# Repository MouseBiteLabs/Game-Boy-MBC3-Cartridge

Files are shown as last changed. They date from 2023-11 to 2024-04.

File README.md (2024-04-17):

# Game Boy MBC3 Cartridge

This is my design of a flashable MBC3-based cartridge for the Game Boy. The MBC3 mapper improves a lot over the MBC1, and includes a real-time clock for everyone's favorite battery-sucking game.... Mary Kate and Ashley Pocket Planner! Oh, and Pokemon.

This circuit board should cover most, if not all, MBC3 games. The features are as follows:

- Able to make games up to 2 MB in size, that use up to 256 Kbit of RAM
- Compatibility with all four of the popular Game Boy battery management ICs - MM1026, MM1134, BA6129, and BA6735
- The option to add battery backup to the cartridge *without* the need of the original battery management ICs
- Fully compatible with the <a href="https://www.gbxcart.com/">GBxCart RW</a> so you can transfer games and save files to and from the board
- 
assemblepic

boardscan3

All gerbers and source files can be found in this repo, as this project is fully open source. Technical documentation of the board can be found in the Technical folder.

## Important Things Before You Start

1) To use this board, you need to have an original Game Boy game that uses an MBC3 mapper chip. <a href="https://catskull.net/gb-rom-database/">You can find a list of games and their mappers here</a>. Use the search function. Please note the RAM is in bytes, not bits. Since SRAM in this repo is defined in bits, you need to convert by multiplying the number of bytes by 8.
2) You will need to remove the MBC3 from your donor cartridge for use on this board. This will require a hot air rework station or a hot plate. There's a list below of other parts you can re-use from the donor cartridge.
3) When soldering parts on, it's a good idea to put kapton tape or otherwise cover the bottom cartridge edge. You do not want to get solder on the cartridge contacts.
4) I am not responsible for any damage you do to your self or your property. Attempt this project at your own risk.
5) I do not guarantee design compatibility. You may encounter issues with certain games. There is also a chance I have made an error in the design or the BOM - if this is the case, I will do everything I can to address the problem as quickly as possible.
6) If you are using this board to make games other than for personal use, you must have permission from the originator to use and distribute any ROM images or other related material. You are responsible for making sure you adhere to any license requirements.

DO NOT use my circuit boards for profiting from stolen work - this especially includes homebrew content, ROM hacks, and using fan-made labels without permission from the originator. **Support original creators!**

## Board Characteristics and Order Information

The zipped folder contains all the gerber files for this board. The following options **must** be chosen when ordering boards for yourself.

- Thickness: 0.8mm
- Surface Finish: ENIG
- Gold Fingers: Yes, 30° chamfer

**Add this note to orders:** "The milling.gbr layer indicates where an unplated slot should be added to the board. Please add an unplated slot as indicated."

**I sell this blank circuit board on Etsy, so you don't have to buy a bunch of multiples if you don't want to.** (Click the banner!)

<a href="https://mousebitelabs.etsy.com/listing/1605239014/game-boy-cartridge-pcb-mbc3">PCB from Etsy</a> 

You can use the zipped folder at any board fabricator you like. You may also buy the board from PCBWay using this link (disclosure: I receive 10% of the sale value to go twoards future PCB orders of my own):

<a href="https://www.pcbway.com/project/shareproject/Game_Boy_MBC3_Cartridge_a4f7b749.html">PCB from PCBWay</a>

<a href="https://oshpark.com/shared_projects/6rPI4Bk8">The board is also listed on OSH Park as well.</a> **Be sure to get them in 0.8mm thickness if you order from here.**

## Required Equipment

The EEPROMs on the board needs to be programmed somehow. I recommend using the GBxCart, as mentioned. These boards are fully compatible with it, and it makes reflashing games extremely easy using <a href="https://github.com/lesserkuma/FlashGBX">lesserkuma's FlashGBX software</a>.

Alternatively, you can buy an EEPROM programmer with a TSOP adapter. The downside to this method is that you have to desolder the chip every time you want to program it. The <a href="https://flashcatusb.com/">FlashcatUSB</a> is one popular option in retro spaces.

## Battery Safety

When assembling a board, I recommend populating all the parts *except* the battery, and getting it to run initially without it. This is to make it easier to fix any solder connections that might need fixing, without having to worry about getting the battery hot. And if you need to rework anything near the battery after you've put it on the board, be safe and remove it before putting a hot soldering iron next to it.

And this should go without saying, but if you're assembling these boards with a hot plate or hot air, *do not* solder the battery on this way. You should use an iron, and keep heat off of the battery as much as possible. 

(Also check polarity!)

## Board Configurations

The board comes with five sets of jumper pads for solder bridges. SJ3, SJ5, and SJ6 require you to solder bridge the middle pad either to the left or right pads. SJ1 and SJ4 are configured by either leaving them alone or bridging them with solder. Here are the situations where you need to add solder bridges.

### Making Games Without SRAM or Battery (SJ1 and SJ4)

Solder bridge SJ1 and SJ4 if your game does not use any SRAM or battery. I don't believe there were ever any MBC3 games made *without* SRAM, but if you wanted to... remove it for some reason, you can.

### MBC3 Type Select (SJ3)

The MBC3 chip you use from the donor cartridge can be one of a few different types:

- If your MBC3 doesn't have a revision letter on it (it just says "MBC3" on it) then bridge the middle pad of SJ3 to the left. (You will also need to populate Q1!)
  - If you're using a revision-less MBC3, and are making a game that requires a battery, you should use a donor MM1026, MM1134, BA6129, or BA6735 battery management IC instead of the replacement TPS3613.
- If your MBC3 *does* have a revision letter, such as MBC3A or MBC3B, then bridge the middle pad of SJ3 to the right.



*[Images of MBC3 chips from <a href="https://gbhwdb.gekkio.fi/cartridges/mbc3.html">Game Boy Hardware Database</a>.]*

### RAM Size Selection (SJ5 and SJ6, or SW1)

These jumpers are located underneath the MBC3 chip, and labeled "64K" and "256K". Solder them to configure the amount of RAM your cart uses. You must configure these pads for every game you make, unless you do not need RAM. <a href="https://catskull.net/gb-rom-database/">You can find a list of games here with their respective RAM sizes.</a>

- If the game you're making uses 256 Kbit of RAM, then solder the middle pads of the two jumper sets to the right pads.
- If the game you're making uses 64 Kbit of RAM, then solder the middle pads of the two jumper sets to the left pads.
- SJ5 and SJ6 must be soldered in the same direction.
- The footprint of these selection pads should allow for a DPDT switch, part number CAS-220A1, to be placed on these pads instead of having to bridge the pads with solder.

Note that you can make games that only require 64 Kbit of RAM and still use a 256 Kbit SRAM chip. You still need to configure the jumpers to the 64 Kbit setting, though.



### Games Without a Real-Time Clock

If your game does *not* use the RTC function with the crystal X1, then you need to bridge the pads of Z1 (which is called C3 on v1.3 and earlier).



## Test Points and Final Checkout

On the back of the board are five test points. Here's where they are connected:

- TP1: SRAM supply voltage
- TP2: Battery voltage (after R1)
- TP3: Battery voltage (positive terminal of battery)
- TP4: Ground
- TP5: VCC input voltage

After you assemble your game, you should measure the current out of the battery. But first, you should program it with the GBxCart, or if you programmed the EEPROM separately, put it into a Game Boy and cycle power once. Then, flip the PCB upside down on a non-conductive surface (not your leg), and set your multimeter in DC millivolts (or volts). Put the positive probe on TP3 and the negative probe on TP2. If you used a 10kΩ for R1, as indicated in the BOM, you should read a voltage in the single or tens of millivolts for non-RTC games, or up to 40 mV for games using a real-time clock. If you have something much higher, especially voltages above 40mV, then you likely have an issue or short circuit on the board somewhere.

**Note: You need to power up the game at least once before battery currents will make sense - the battery management ICs can start up in an unknown state before applying main power to the board.**

To estimate battery life, see <a href="https://github.com/MouseBiteLabs/Game-Boy-MBC3-Cartridge/tree/main/Technical#estimating-battery-life">this section in the Technical Design Document</a>, or for more in-depth analysis, <a href="https://hackaday.io/project/11864-tritiled/log/72554-determining-maximum-runtime-176-to-202-years-cr2032">this Hackaday post</a>.

### Current Draw Measurements

The revision of MBC3 chip you are using will influence the current draw out of the battery when the game is off, and thus how long your battery life will last. Using the real-time clock function on the MBC3 will draw more current than if you do not.

For the test set up, I am replacing the battery with a regulated DC power supply set for 3 VDC for consistency, on a cart board with an MM1134 chip for U4, and brand new AS6C62256 SRAM. The "no RTC" measurements have Z1 (or C3) shorted, and the "with RTC" measurements have R2, C2, Z1, and X1 populated. I am using a Fluke 117 Multimeter in DC mV mode for measurements.

| Rev | P/N | Current draw (without RTC) | Battery Life Estimate (no RTC, CR2025) | Current draw (with RTC) | Battery Life Estimate (RTC, CR2025)  | Battery Life Estimate (RTC, CR2032) |
| ----- | --- | --- | --- | --- | --- | --- |
| MBC3  | LR385364 | 0.2 uA | >50 years | 1.8 uA | 10 years | 14 years |
| MBC3  | BU3631K  | 0.6 uA | 31 years | 1.6 uA | 12 years | 16 years |
| MBC3  | P-1 | 0.4 uA | 47 years | 3.8 uA | 5 years | 7 years |
| MBC3A | LR38536B | 0.2 uA | >50 years | 1.5 uA | 13 years | 18 years |
| MBC3A | BU3632K  | 0.5 uA | 37 years | 1.5 uA | 13 years | 18 years |
| MBC3A | P-2 | 0.5 uA | 37 years | 3.9 uA | 5 years | 7 years |
| MBC3B | BU3634K  | 0.6 uA | 31 years | 1.5 uA | 13 years | 18 years |
| MBC3B | P-2 | 0.4 uA | 47 years | 3.7 uA | 5 years | 7 years |

*Note: The SRAM I used, AS6C62256, drew 0.05 uA by itself for these tests. Your current draw may vary depending on the SRAM you are using.*

### Why not FRAM?

This board is only suitable for using SRAM. One downside to SRAM, if you haven't figured it out yet, is that you need a battery to keep the SRAM powered on even when the game is turned off. So eventually the battery will die, and your save data is lost. Some people have used FRAM, or Ferroelectric RAM, to keep save data around even after the battery dies (specifically, the popular part that's used for FRAM carts is the FM18W08). But, using this FRAM chip has a handful of downsides, and the benefit of keeping save data after the battery dies *in my opinion* does not outweigh the cons, which are as follows:

1) Quality, new stock, 5V tolerant FRAM is expensive ($12+ per part).
2) Cheaper FRAM chips from eBay or Aliexpress are notoriously flaky (anecdotally, ~50% success rate).
3) FRAM memory access requires different chip select timing than SRAM, and the Game Boy expects SRAM, so it is not natively compatible with FRAM carts. The Gameboy Color specifically cannot (easily) be made to properly access FM18W08 chip. You *can* use an OR gate and add the CLK on the cart edge to try to achieve the necessary timing, but it only works (properly) for DMG/MGB/SGB, not the GBC. It usually *works* in practice for GBC, but it's technically a datasheet violation and can potentially cause issues in edge cases. <a href="https://github.com/Gekkio">(Thanks to gekkio for pointing this out!)</a>

Brand new SRAM chips are ~$3, and having the SRAM footprint also allows you to use SRAM from an original cart if desired. And other than the scenario where you are making a game with a real-time clock and are using an inefficient MBC3 variant (P-1 or P-2), you can easily get more than a decade of battery life. You're already assembling this cartridge; you can dump the save and replace the battery!

Note that this isn't to throw shade at any FRAM-based carts, but for me personally, it's more trouble than it's worth. If you just *need* FRAM, you can find other cart designs out there that have it, <a href="https://retrogamerepairshop.com/products/game-boy-2mb-32kb-fram-mbc3-with-rtc-flash-cartridge-by-hdr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">like this one!</a>

## Board Fitment

The shape of this board was originally meant to mimic original Game Boy circuit boards as closely as possible (v1.3 and earlier). Unfortunately, when placed in some aftermarket Game Boy cartridge shells (like those from Cloud Game Store), the circuit board has a lot of freedom to rotate around the main screw hole in the bottom-middle of the cartridge. This can cause misalignment when you put it in a Game Boy, which can cause a game to either not load properly (garbled Game Boy logo) or shut off the Game Boy because of a short circuit. This isn't *dangerous* or anything, just annoying.

In order to make the boards fit nicer in any kind of shell, for v1.4 I added extended tabs of circuit board material to the edges of the cartridges to keep it from rotating too much in shells, which was suggested to me by <a href="https://github.com/orangeglo">orangeglo</a>! (Thanks!)

If you're having trouble fitting the circuit board into a shell, because the tabs interfere with the cart edges, you can safely sand or trim them down as there is no copper within the tabs themselves. The only shell that appears to require any kind of trimming are Kitsch-Bent shells.

## Bill of Materials (BOM)

Your parts list will vary depending on the game you are trying to make, and what chips you have for the battery management (if any). **You cannot use both U4 and U5 - you must choose one or the other.** U4 comes from a donor cartridge, and U5 is a readily available aftermarket option.

Please carefully review the parts you need for the board you are trying to make. Do not add any parts to your build that don't appear in the column for the game you are making. This means you *cannot* populate every component on the board at the same time.

**NOTE: If you are *not* using the RTC function of the MBC3, you need to bridge the pads of Z1 (or C3) with solder.**

| Reference Designators | Value/Part Number | Package | Description | No save carts | Save carts with U4 | Save carts without U4 | Source |
| --- | --- | --- | --- | --- | --- | --- | --- |
| B1 | CR2032, CR2025, CR2016 | CR2032 | Backup Battery | | x | x | [https://mou.sr/3SeAzfT](https://mou.sr/3SeAzfT) |
| C1 | 0.1uF | 0603 | Capacitor (MLCC) | x | x | x | [https://mou.sr/3ENc15O](https://mou.sr/3ENc15O) |
| C2 | 15pF | 0603 | Capacitor (MLCC) | | If using RTC | If using RTC | https://mou.sr/3PPorjO |
| Z1 (or C3) | 15pF | 0603 | Capacitor (MLCC) | | If using RTC | If using RTC | https://mou.sr/3PPorjO |
| C4 | 0.1uF | 0603 | Capacitor (MLCC) | | x | | [https://mou.sr/3ENc15O](https://mou.sr/3ENc15O) |
| C5 | 0.1uF | 0603 | Capacitor (MLCC) | | x | x | [https://mou.sr/3ENc15O](https://mou.sr/3ENc15O) |
| C6 | 10uF | 0603 | Capacitor (MLCC) | | x | x | [https://mou.sr/3mZtSkF](https://mou.sr/3mZtSkF) |
| C7 | 0.1uF | 0603 | Capacitor (MLCC) | x | x | x | [https://mou.sr/3ENc15O](https://mou.sr/3ENc15O) |
| C8 | 0.1uF | 0603 | Capacitor (MLCC) | | | x | [https://mou.sr/3ENc15O](https://mou.sr/3ENc15O) |
| Q1 | 2N7002 | SOT-23 | N-Channel FET | | If MBC3 no rev | x | [https://mou.sr/3rgfh6J](https://mou.sr/3rgfh6J) |
| R1 | 10k | 0603 | Resistor | | x | x | [https://mou.sr/3riR7IH](https://mou.sr/3riR7IH) |
| R2 | 330k | 0603 | Resistor | | If using RTC | If using RTC | [https://mou.sr/3PZ2pvj](https://mou.sr/3PZ2pvj) |
| R8 | 10k | 0603 | Resistor | x | x | x | https://mou.sr/3riR7IH |
| R9 | 130k | 0603 | Resistor | | | x | [https://mou.sr/3MjXliy](https://mou.sr/3MjXliy) |
| R10 | 49.9k | 0603 | Resistor | | | x | https://mou.sr/3Q3NRZO |
| U1 | 29F016, 29F032, 29F033 | TSOP-48, TSOP-40 | Flash EEPROM | x | x | x | AliExpress or eBay |
| U2 | MBC3 | QFP-32 | MBC3 Mapper | x | x | x | Donor MBC3 Game Boy cartridge |
| U3 | AS6C6264, AS6C62256 | SOP-28 | SRAM | | x | x | [https://mou.sr/450klcY](https://mou.sr/450klcY) |
| U4 | MM1026, MM1134, BA6129, BA6735 | SOIC-8 | Battery Management | | x | | Donor Game Boy cartridge |
| U5 | TPS3613 | MSOP-10 | Battery Management | | | x | [https://mou.sr/45Ir2kh](https://mou.sr/45Ir2kh) |
| X1 | 32.768 kHz | Radial | Crystal Oscillator | | If using RTC | If using RTC | https://mou.sr/3ZteKuy |

*Note that C9 - C11 footprints are only included on the board for strange edge cases that may require them sometime in the future; do not populate! See the technical design document for more information.*

### Usable Donor Cartridge Parts

You can use a few parts from the donor cart on the new board to save some money. Note that you will generally get better reliability with new parts as opposed to old ones. For example: I have seen failed RAM chips from donors in the past.

1) **C1/Z1, C2, R2, X1: RTC Components** - You can move over these parts if you're using the real-time clock function. The two capacitors are the same value, so they are interchangeable. On games that *don't* use the RTC, you can't move "Z1" over, because it's a resistor on those boards. Also be careful that on my board, the RTC capacitors are designated as "Z1" (or "C3") and "C2" - don't accidentally move the wrong capacitors over from the donor board to these spots!
2) **U2: MBC3** - This one is required
3) **U3: SRAM** - You can use this part *only if* the game you're making uses the same or less amount of RAM that the donor cartridge does
4) **U4: Battery Management IC** - Using this is probably preferred over the TPS3613 because it'll save you money and parts to put on

You could probably transfer over most of the 0.1uF capacitors but they're pretty cheap anyway, so I generally just recommend buying new resistors and capacitors.

### Capacitors C9 to C11

If you want to experiment with the capacitors C9 to C11, see this info below. **Be aware that adding these components in some of my tests actually ***stopped*** games from working, so again, assume that if you have a problem it lies elsewhere first, because it almost certainly does.**
- C9 is a capacitor connected nearby the SRAM's /WE pin to GND. These were populated on some cartridges, and I believe have a value of approximately 1 nF (0.001 uF) based on measurements from an MBC1 board that used it.
- C10 is a capacitor connected from the cart edge /RESET pin to GND. A spot for this capacitor was included on some MBC1 carts, but I cannot locate an instance of it actually being used when looking through the gbhwdb. It does not appear on *any* MBC3 boards. I don't actually know what value this capacitor would need to be, so I am guessing 1 nF.
- C11 is a capacitor that I have added that was not used on any original Game Boy board. It connects to the SRAM's /CE pin, bypassing to GND. I have added this in the event incompatibilities arise with newer SRAM chips that have much faster speeds than older SRAM chips. This was a problem I encountered on some of my NES cartridges, so this is here just in case, but I have not found an instance where it's required.

## Things to Remember

- The footprint for the EEPROM is specifically for 29F016 - it has 48 pins. However, 29F032 and 29F033 are only 40 pin devices. They still work fine on the board though - place them in the center of the footprint, and leave the outer two pins on each corner empty
- The 29F016, 29F032, and 29F033 have been known to occasionally be defective upon arrival. They're either used, or new old stock, and usually only available from AliExpress.
- The footprint for the battery can fit a CR2032, CR2025, or CR2016 with solder tabs. The only difference is the mAh capacity (larger number = longer life). If you get Panasonic tabbed batteries, you may have to trim the battery tabs to make them fit on the footprint.
  - For untabbed coin cells, you can find battery retainer adapters online, <a href="https://retrogamerepairshop.com/products/hdr-game-boy-game-battery-retainer?variant=40511013290156">like this one,</a> but only for board revision v1.4. It will not fit on earlier revisions.
- For battery management, use either U4 *or* U5 and supporting components. **Do not** use U4 and U5 simultaneously on one board. They will interfere with each other.
- Generally, ROM sizes are conveyed in terms of kilo**bytes** and mega**bytes** (KB, MB). RAM size is usually conveyed in terms of kilo**bits** or mega**bits** (Kbit, Mbit). You can convert Kbit and Mbit to KB and MB by dividing Kbit or Mbit by 8. For example, 256 Kbit = 32 KB.
- You only need to provide ROM and RAM chips that have at least *or greater* the size of the game you are trying to make. That means you can use a 256 Kbit SRAM chip for a game that only requires 64 Kbit of RAM!

## Labels

If you want a Bucket Mouse branded label for your cartridge, look no further than <a href="https://krizdingus.com/mousebitelabs/">krizdingus's designs</a>. Special thanks to Kris for designing these, they look awesome! (If you are going to order/print these, use the high-res images hosted on his website, and *keep the labels for personal or non-commercial use only.*)



## Revision History

### v1.4
- Changed "C3" to "Z1"
- Reduced cart edge by 0.1 mm for better fitment
- Adjusted battery placement to support more battery holders
- Added tabs on the board edges to allow the circuit board to fit better in aftermarket cartridge shells

### v1.3
- Extended cart edge down by 0.25 mm for better fitment
- Added OSHW logo and "SUPPORT ORIGINAL CREATORS!"

### v1.2
- Replace non-donor battery management circuitry with a TPS3613-based circuit for smaller BOM and easier routing

### v1.1
- Moved all parts on the top down to allow for compatibility with DMG-style shells
- Rotated battery for more space
- Widen SRAM footprint for easier soldering
- Renamed some reference designators for consistency between designs
- Changed silkscreen for clarity

### v1.0
- Prototype revision

## Resources and Acknowledgements

- <a href="http://www.devrs.com/gb/files/hardware.html">Jeff Frohwein's GameBoy Tech Page</a>
- <a href="https://gbhwdb.gekkio.fi/">Game Boy Hardware Database</a>
- <a href="https://catskull.net/gb-rom-database/">Nintendo Gameboy Game List</a>
- <a href="https://www.gbxcart.com/">insideGadgets discord server for GBxCart RW compatibility requirements</a>
- <a href="https://github.com/lesserkuma/FlashGBX">Lesserkuma's FlashGBX software</a>
- <a href="https://www.alldatasheet.com/datasheet-pdf/pdf/99104/MITSUBISHI/MM1026.html">System Reset IC Datasheet</a>
- <a href="https://www.ti.com/lit/ds/symlink/tps3613-01.pdf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">TPS3613 Datasheet</a>
- Board outline modified from <a href="https://tinkerer.us/projects/homebrew-gameboy-cartridge.html">Dillon Nichols's Homebrew Gameboy Cartridge project</a>
- Thanks to <a href="https://github.com/orangeglo">orangeglo</a> for his suggestion of adding spacers around the board edge for better fitment in aftermarket cartridges
- Some components from <a href="https://github.com/adafruit/Adafruit-Eagle-Library">Adafruit's Eagle parts library</a>
- Some components from <a href="https://www.snapeda.com/">SnapMagic</a>
- Thank you to <a href="https://github.com/Gekkio">gekkio</a> for their deep Game Boy knowledge resources, and for collaboration in demystifying some of the design choices on Game Boy cartridges
- Thanks to the awesome members of the <a href="https://moddedgameboy.club/">Modded Gameboy Club</a> for their feedback and support during the entire project development

## License

<br />This work is licensed under a <a rel="license" href="http://creativecommons.org/licenses/by-sa/4.0/">Creative Commons Attribution-ShareAlike 4.0 International License</a>. You are able to copy and redistribute the material in any medium or format, as well as remix, transform, or build upon the material for any purpose (even commercial) - but you **must** give appropriate credit, provide a link to the license, and indicate if any changes were made.

©MouseBiteLabs 2023

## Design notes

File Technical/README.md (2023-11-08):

# Technical Design Document

This write-up will serve as an attempt of explaining some of the features on this cartridge. I won't go into heavy detail about the functionality of the MBC3, but I will attempt to explain some higher level functions and the reasoning behind the circuit.

Please correct me on any information I may have gotten wrong.

## Schematic



## Cart Edge Pins

Very briefly, I will categorize the different pins on the 32-pin cartridge edge connector.

- Pin 1 and pin 32 are VCC and GND, respectively.
- Pin 2 is the CLK or PHI pin, which is solely connected to the CLK pin on the MBC3 chip.
- Pin 3 is the /WR pin and pin 4 is the /RD pin. These signals partially determine when data is read from the ROM or when data is read/written to the RAM.
- Pin 5 is the /CS pin, which is unused on MBC3 carts.
- Pins 6 through 21 are the address pins A0 through A15.
- Pins 22 through 29 are the data pins D0 through D7.
- Pin 30 is the /RST (or reset) pin. When this pin is low, the Game Boy will cease operation.
- Pin 31 is a generally unused pin in Game Boy cartridges, but here it is connected to the EEPROM's /WE pin for compatibility with the GBxCART RW.

## MBC3 - Memory Bank Controller

The MBC3 is a memory mapping chip, used to expand the addressable memory space of a Game Boy cartridge. The RA14-RA20 and AA13-AA14 outputs are used to access higher memory banks on the ROM and RAM chips. It also has a positive and negative RAM chip select output to control data access on the RAM, though only the RAM /CS output is commonly used. The main upgrade over the MBC1 other than addressable memory space is the addition of a real time clock, or RTC, for time-based games like Pokemon GSC and Mary Kate and Ashley's Pocket Planner. The downside to the RTC is that it *greatly* increases the current draw of the MBC3 when operating on battery power, which is why your older Pokemon Red might still be holding a save, while your Pokemon Silver died a decade ago.

Further sections will provide more context for some of the MBC3 pins and the logic of how they are connected.

## ROM and RAM

The connections to the address and data pins here are mostly self-explanatory. However, the upper address pins on the ROM and RAM chips are controlled, or "banked", by the MBC3.
- A14 through A20 on the ROM chip are controlled by the RA14 to RA20 outputs from the MBC3.
- A13 and A14 on the RAM chip are controlled by the AA13 and AA14 outputs from the MBC3.
  - SJ5 and SJ6 are solder jumpers that must be set to match the size of the SRAM chip you're using. See the main README for information. The function of these jumpers is mostly to set a 64K SRAM chip's CE2 pin to the correct location for proper control (more information in later sections). 
 
Other pins include:

- The ROM's /CE pin is controlled by the A15 address pin and the /OE pin is controlled by the /RD pin on the cart edge (pin 4).
- The ROM's /WE pin, which was not on original cartridges, is connected to pin 31 on the cart edge for programming via the GBxCART RW as previously mentioned.
- The RAM's /OE pin is connected to the /RD pin on the cart edge (pin 4).
- The RAM's /WE pin is connected to /WR on the cart edge (pin 3).
- The RAM's /CE pin requires a bit of explanation, which will be covered in a later section.

## Battery Management and Data Retention Considerations

Ensuring current coming out of the battery is as minimal as possible while the Game Boy is turned off is crucial for long-lasting save data. The higher the current, the lower the battery life! But we need to do this without breaking compatibility with normal operation. So here are the things we need to keep in mind:

1) SRAM must have continuous power to retain save data.

2) Data on the SRAM must be accessible during normal gameplay.

3) The number of battery-powered current-consuming components should be minimized, and those that are powered must use as little current as possible.

4) Operation while the voltage is ramping down after turning off the power switch must be restricted to prevent junk data from being written to cartridge RAM.

Original MBC3 carts manage all of this with U4 - MM1026/BA6129, or MM1134/BA6375. I'll go over the functional requirements here, and for convenience, I'll be using the MM numbers when talking about them.

### SRAM Operational Background

For most Game Boy games, there were two main sizes of SRAM chips used - 64 Kbit and 256 Kbit (further refered to as just 64K or 256K). The pinouts of these two types of chips are nearly identical: 



The big differences are the number of address pins and the number of chip enable pins. The 64K chip has 13 address pins and two chip enables (/CE and CE2), and the 256K chip has 15 address pins and one chip enable (just /CE). The additional address pins on the 256K SRAM gives it more memory, but one of the chip enable pins had to be sacrificed to accommodate this. This is kind of important, because the chip enable pins influence two main things - they tell the chip when data is being accessed, *and* how much current the chip is drawing during standby. For 64K SRAM chips, that's pretty easy - use one chip enable pin for data access, and the other for data retention mode. But for 256K SRAM, you have to do both of those functions at once. Look at the requirements for the low "data retention current" on the AS6C6264 datasheet and the AS6C62256 datasheet:



For 64K, /CE needs to be at VCC, *or* CE2 needs to be at GND for the current to be minimized. For 256K, /CE needs to be at VCC, full stop (in this case, VCC is whatever voltage appears on the SRAM's VCC pin, so when power is off that's the battery voltage). That's not super convenient if the power is off - something needs to make the /CE pin go to VCC, which means whatever that something is better not be pulling a lot of current, lest we lower our battery life.

On original MBC3 cartridges, by my findings after looking at cart images on gbhwdb, on all boards except DMG-LFDN-01 the MBC3 is powered via the battery management IC along with the SRAM. This is a common occurance because MBC3 games utilized a real-time clock, which needs the MBC3 to be powered while out of the Game Boy to retain the time. Since the MBC3 is powered by the battery, this means the MBC3 can provide the signals necessary to drive the CE2 or /CE pins on the SRAM to ensure low power draw while idling. The battery management IC, U4, is used to keep the /RESET and the /WP (or /SHDN) low while power is off.

For the LFDN-01 board where the MBC3 is powered by the 5V supply only (it doesn't use the RTC function), the /CE pin of the 256K SRAM on-board is gated by a NAND to keep it high while power is off - the inputs to the NAND device are pin 21 on the MBC3 (implied to be positive RAM CE output) and pin 3 of the BA6129, the CS output which is high during regular gameplay and GND when the game is off.

On my custom MBC3 board, I include compatibility with the MM and BA chips, as well as an option with completely new off-the-shelf components without the need for a donor. But before covering that, let's talk about the other important part of the battery backup system - how to properly and safely manage shifting between console power to battery power.

### Reset IC - MM1026

When you turn the power switch off on a DMG, the voltage on the VCC supply will ramp down. However, the DMG CPU requires 5 V to operate properly. A sufficiently lower voltage supplying the CPU may cause erroneous operation on the I/O pins of the CPU, even for a brief period of time. This can corrupt data stored on the SRAM of the game cartridge, say if the CPU accidentally writes junk data to part of the memory. This is bad! 

In order to prevent this, cartridges that have battery-backed SRAM on them use the battery management chip U4 to shut down operation of the CPU on pin 30 of the cart edge - the /RST (or /RESET) line. Asserting this to GND will stop all operation on the I/O pins, preventing corruption from occuring. According to the MM1026 datasheet, the /RESET output and CS output pins will be GND whenever voltage on the VCC pin is below 4.2V.

*Please note that the MM1026 has a /RESET output pin, but this is not the same as the Game Boy CPU /RESET input, the MBC3 /RESET input, or the cart edge /RST pin 30! I will call the MM1026's pin 2 the "Reset output pin" from now on for clarity.*



But that's not all the MM chip does. It also is used to pull the MBC3's /RESET input to GND as well. This is especially important as keeping this pin off will keep current draw of the MBC3 to a minimum. Furthermore, pulling this pin to GND also causes the MBC3 to assert the SRAM's /CE pin high to keep the SRAM in a low power state.

### Reset IC - MM1134

The MM1134 is nearly identical to the MM1026, with one distinct difference. There is one extra input that was previously an unconnected pin on the MM1026 - the /Y input. This input is intended to be used with a RAM /CE signal. It controls the /CS output (pin 5) on the MM1134. See the schematic and timing diagram below:



Essentially, the /CS output will follow the /Y input, *unless* VCC is below the 4.2V power-off threshold. Then, /CS will be pulled to VOUT (the combination of VCC and VBAT). Hey, this is great, because it means we can control that pesky 256K SRAM /CE pin *and* put it in a low power state when the power shuts off!

*Note: If you ground the /Y input, then the MM1134 will act exactly like an MM1026.*

From looking at carts on gbhwdb, it seems like this distinctive difference of the MM1134 vs. the MM1026 is unused. As the MBC3 is usually powered on the battery anyway, this functionality is fulfilled by the MBC3 itself.

### Open Collector Requirements on CPU /RESET Input

One minor, but important, note that drives a few design choices - there are actually two outputs on the MM1026/MM134 that go low when power is below 4.2 V. One of them is open collector (pin 2, the "Reset output"), and one is instead driven high by an internal transistor or pulled low by an internal pull-down (pin 3, the "CS output"). This is important because it means *you cannot safely use the CS output pin to control the Game Boy's /RESET line.*



On the DMG, the CPU's /RESET input is also connected to half of the power switch. When the switch is fully turned off, the /RESET input is pulled to GND directly.



*[Image adapted from <a href="https://github.com/Gekkio/gb-schematics/blob/main/DMG-CPU-06/schematic/DMG-CPU-06.pdf">gekkio's DMG CPU board schematic</a>]*

This means that to ensure no damage is done to the battery management chip, any output connected to the Game Boy's /RESET input must be **open collector**. Open collector outputs can either float their output, or (in this case) pull it to GND - reference the "Pin 2 Reset Output" schematic above. That means pulling it to GND with the power switch won't damage anything internal to the chip, it will just safely bypass the pin's function.

But, in the case of pin 3 on the MM chips, the "CS output" pin, imagine a scenario where the power switch was turned off, but the capacitors on the board have not yet discharged down to 0V. This means there'd still be some residual voltage on the VCC net. But, the CS output pin is connected to VCC via the transistor internal to the chip, and if VCC hasn't dropped far enough, then this would still be pulled high to VCC. So if you had connected pin 3 to the /RESET input on the Game Boy, in this scenario, there would be a path from VCC on the MM's supply pin, *through* the transistor on pin 3, through the power switch on the DMG, to GND - short circuiting the capacitors on the board. This means that for a moment, the internal transistor driving pin 3 would experience a surge of current. Since the output is not designed to do that, it could cause damage to the part. So let's avoid that situation!

In conclusion, any output connected to the /RESET net on the Game Boy *must* be open collector.

*On the GBC, they added a chip that pulls the /RESET line to GND through an open collector output whenever the voltage on VCC drops below 3.5 V, instead of using the power switch to ground the input. If the DMG had this, maybe Nintendo wouldn't have needed these MM chips but could use something a bit simpler. But we must design cartridges with DMG compatibility in mind!* 

## Battery Management Implementation Options

Ok, with the background taken care of, I'll talk about how my MBC3 board manages all of this, and the different compatibility options. If you reference the schematic above, you will see two options for games that use SRAM:
1) MM1026 or MM1134 ("Group A" components)
3) No donor MM chip ("Group B" components)

### Using an MM Chip

For reference again, here is a pinout diagram of the MM1026 and MM1134.



And here is the section of the schematic for using one of these chips ("Group A" components).



#### Creating the Battery-Backed Power Supply

The VOUT pin is a combination of the VCC and VBAT pins. VCC is connected to the Game Boy's 5V supply, and VBAT is connected to the battery (through a current-limiting resistor). When VCC drops below 3.3V during power-down, the MM chip switches VOUT to be supplied by VBAT instead of VCC. Conversely, when it passes above 3.3V during power-on, the MM chip switches VOUT to be supplied by VCC instead. This guarantees constant power to the SRAM to keep save data retained at all times, assuming the battery is not dead.

#### Reset Pin Management

Because anything connected to the /RESET input pin on the cart edge must be open collector, the open collector output of the MM chip, pin 2, is connected to the /RESET cart edge pin (pin 30). The MBC's /RESET input, pin 4, can be connected one of two ways, based on how SJ3 is soldered.



For revision-less MBC3 chips, it's recommended to populate Q1 and bridge SJ3 to route the MBC3's /RESET input to the cart edge pin 30 (net label /RST). Q1's gate is driven by pin 5 output of the MM chip (net CSB), which is high whenever VCC falls below 4.2V. This essentially actively keeps the /RESET line low when power is off, and allows the console to assert the /RESET input of the MBC3. This FET circuit is seen on DMG-KECN-SP boards, which use a revision-less MBC3 boards. The reason this wiring is recommended is unclear - KECN-01 boards use revision-less MBC3 chips and do not include it - but to be safe, it should be added. 

Boards that use MBC3A or B do not have this extra FET, and instead drive their /RESET inputs with the CS output of the MM chip, pin 3.

#### Controlling the SRAM /CE Pin

As mentioned earlier, since the MBC3 is powered on the battery, the RAM /CS output pin can keep the SRAM in a low power state while power is off.

### Using Brand New Components

If you do not have one of these MM chips, as you can only typically get them from donor Game Boy cartridges and not all games use them, you can achieve the same results using commercially-available components. In order to do so, you need to populate "Group B" components which features the TPS3613 - a Texas Instruments chip that is almost identical to the MM1134, with a few minor differences. You also need to solder Q1 onto the board, regardless of your MBC3 revision.



Here is the timing diagram from the TPS3613 datasheet, showing the relations between the inputs and outputs of the chip.



#### Creating the Battery-Backed Power Supply

Like the MM chips, VOUT is created by VCC or VBAT. But instead of a hard internal threshold, the output of this pin is determined by the voltage on the SENSE pin. If the voltage on SENSE is above an internal set voltage of 1.15 V (shown as VIT in the diagram), VOUT is equivalent to VCC. When the SENSE voltage drops below VIT, and when VCC drops below VBAT, VOUT switches over to being powered by VBAT instead.

The voltage on SENSE is determined by the voltage divider made with R9 and R10. The MM chips have an internal threshold of 4.2 V for determining that the power is going off and the /RESET outputs should be asserted to protect the RAM from spurious writes. So for this design, I'll stick to that threshold.

#### Reset Pin Management

The /RESET and RESET outputs of the TPS3613 are push-pull. This is slightly inconvenient, because it means you cannot directly connect them to the /RST pin on the cart edge (pin 30), because as discussed earlier, any connection to this pin must be open collector. So, we just have to make it open collector (or in this case, open drain). Adding Q1, an N-channel MOSFET, achieves this.

- When voltage on the SENSE pin is above the internal 1.15V threshold, the /RESET output pin is asserted high (keeping pin 25 on the MBC3 high), and the RESET output pin is asserted low. The low positive RESET output will keep Q1 off and allow /RST, pin 30 on the cart edge, to be pulled high by the Game Boy internals and allow operation.
- When voltage on the SENSE pin drops below the internal 1.15V threshold, the /RESET output pin is asserted low turning off the MBC3, and the RESET output pin is asserted high. This will turn Q1 on, and pull pin 30 on the cart edge to GND. Note that the positive RESET output follows the voltage on the VDD pin, so once the 5V supply on the Game Boy depletes, Q1 will be off again.
  - The consequence of this is you should use an MBC3A or MBC3B to make games with the TPS3613. As mentioned earlier, revision-less MBC3 chips should be connected such that the /RESET input is connected to cart edge pin 30, and driven by Q1. Because the positive RESET output eventually goes to zero, Q1 will eventually cease to conduct, leaving the MBC3's /RESET input pin floating. This causes excess power draw of the MBC3, which will kill your battery much faster than normal. You need to use the driven /RESET output of the TPS3613 to keep the /RESET input pin of the MBC3 at GND at all times.

#### Controlling the SRAM /CE Pin

The /CEIN input and /CEOUT output pins of the TPS3613 acts exactly like the /Y input and /CS output pins of the MM1134 - /CEOUT will follow /CEIN as long as the voltage on the SENSE pin is above 1.15V. This feature is unused on the MBC3 cart because, again, the MBC3 is powered via the battery which can assert the RAM's /CS pin to keep it in a low power mode.

## Estimating Battery Life

You can get a very rough estimate of battery life by measuring the voltage in millivolts across the battery-series resistor R1. Just use Ohm's Law to find the current: I = V / R where V is the voltage in millivolts you measure and R is the resistance of R1 in ohms. If you use these units, the current will be in milliamps. 

*Fun fact: you can measure this voltage using TP2 and TP3 on the back of the board as your multimeter probe points.*

Then, find the milliamp-hour rating of your selected battery (preferrably from a datasheet). For example, a Renata CR2032 battery is rated for 225 mAh. Take this number and divide by the milliamps calculated above, to get a rough estimate of the number of hours the battery can supply when the console is turned off (when it is on, the Game Boy powers the cart so the battery is unused). Divide by 24 and then 365 (or just divide by 8760) and you will get a number of years. 

So for an overall equation to determine the very approximate number of years the battery will survive:

Years = Resistance of R1 (ohms) * Battery capacity (mAh) / Voltage (mV) / 8760 

For an example: an MBC3 cartridge where R1 is 10 kΩ (or 10000 Ω), using a CR2032 rated for 230 mAh, and a voltage of 20 mV measured across the terminals of R1, yields 10000 * 225 / 40 / 8760 = 12.84 years of battery survival. This number can be different due to changing environmental conditions, self-discharge of the battery, and also actual capacity of the battery - discharging a battery at very small currents will increase its apparent capacity, and as the voltage decreases, the current required for data retention decreases as well.

Just backup your save data within a decade of making the cart and you'll be fine.

## A Few Extra Capacitors

I added spots for a few extra capacitors, in the event some compatibility issues arise. By default, you should ignore these components, as they were not present in most cartridges. If I find instances where they are needed, I will note them in this repo. For now, assume they are unnecessary.



1) C9 is a capacitor connected nearby the MBC3's /WR pin to GND. These were populated on some cartridges, and have a value of approximately 1 nF (0.001 uF).
2) C10 is a capacitor connected nearby the MBC3's /RESET pin to GND. A spot for this capacitor was included on some MBC1 carts, but I cannot locate an instance of it actually being used when looking through the gbhwdb. I don't actually know what value this capacitor would need to be, so I am guessing 1 nF.
3) C11 is a capacitor that I have added that was not used on any original Game Boy board. It connects to the SRAM's /CE pin, bypassing to GND. I have added this in the event incompatibilities arise with newer SRAM chips that have much faster speeds than older SRAM chips. This was a problem I encountered on some of my NES cartridges, so this is here just in case.

## Resources

- <a href="http://www.devrs.com/gb/files/hardware.html">Jeff Frohwein's GameBoy Tech Page</a>
- <a href="https://gbhwdb.gekkio.fi/">Game Boy Hardware Database</a>
- <a href="https://catskull.net/gb-rom-database/">Nintendo Gameboy Game List</a>
- <a href="https://www.gbxcart.com/">insideGadgets discord server for GBxCart RW compatibility requirements</a>
- <a href="https://www.alldatasheet.com/datasheet-pdf/pdf/99104/MITSUBISHI/MM1026.html">System Reset IC Datasheet</a>
- <a href="https://www.ti.com/lit/ds/symlink/tps3613-01.pdf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">TPS3613 Datasheet</a>
- <a href="https://www.alliancememory.com/wp-content/uploads/pdf/Alliance%20Memory_64K_AS6C6264v2.0July2017.pdf">AS6C6264 Datasheet</a>
- <a href="https://www.alliancememory.com/wp-content/uploads/pdf/AS6C62256.pdf">AS6C62256 Datasheet</a>
- <a href="https://github.com/Gekkio/gb-schematics/blob/main/DMG-CPU-06/schematic/DMG-CPU-06.pdf">Gekkio's Game Boy Schematic Resources</a>

## License
<br />This work is licensed under a <a rel="license" href="http://creativecommons.org/licenses/by-sa/4.0/">Creative Commons Attribution-ShareAlike 4.0 International License</a>. You are able to copy and redistribute the material in any medium or format, as well as remix, transform, or build upon the material for any purpose (even commercial) - but you **must** give appropriate credit, provide a link to the license, and indicate if any changes were made.

©MouseBiteLabs 2023

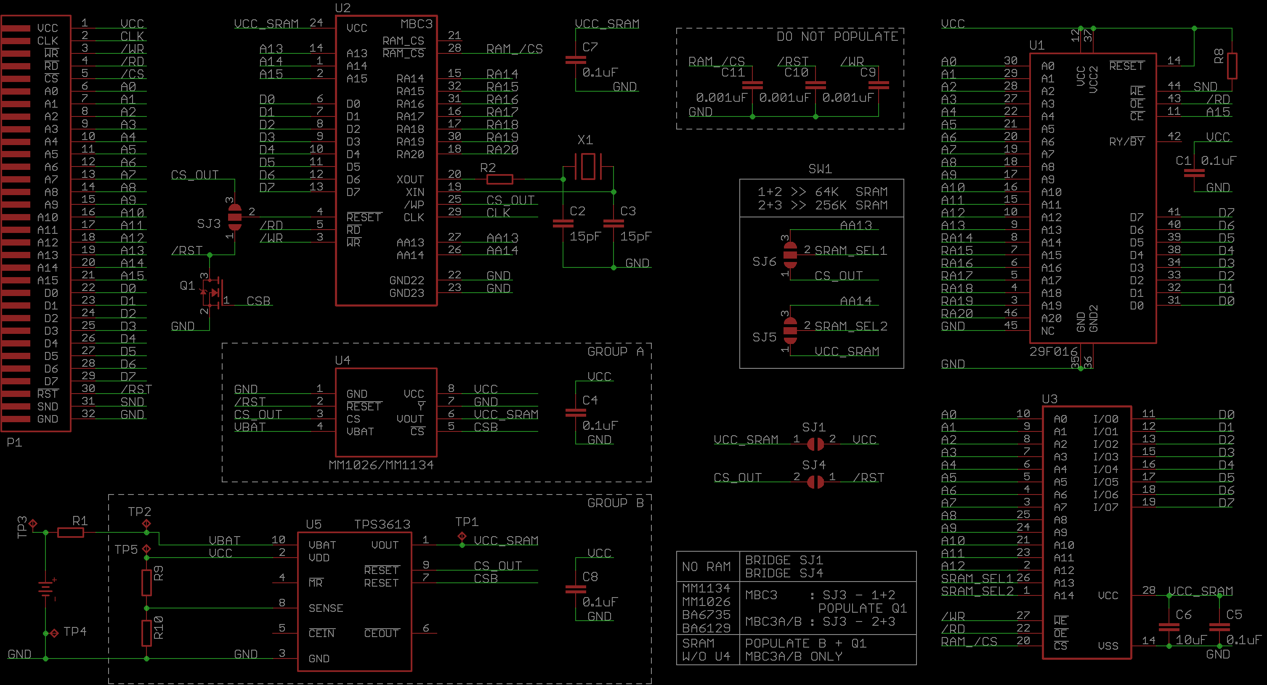
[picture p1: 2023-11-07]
Technical/schematic.png

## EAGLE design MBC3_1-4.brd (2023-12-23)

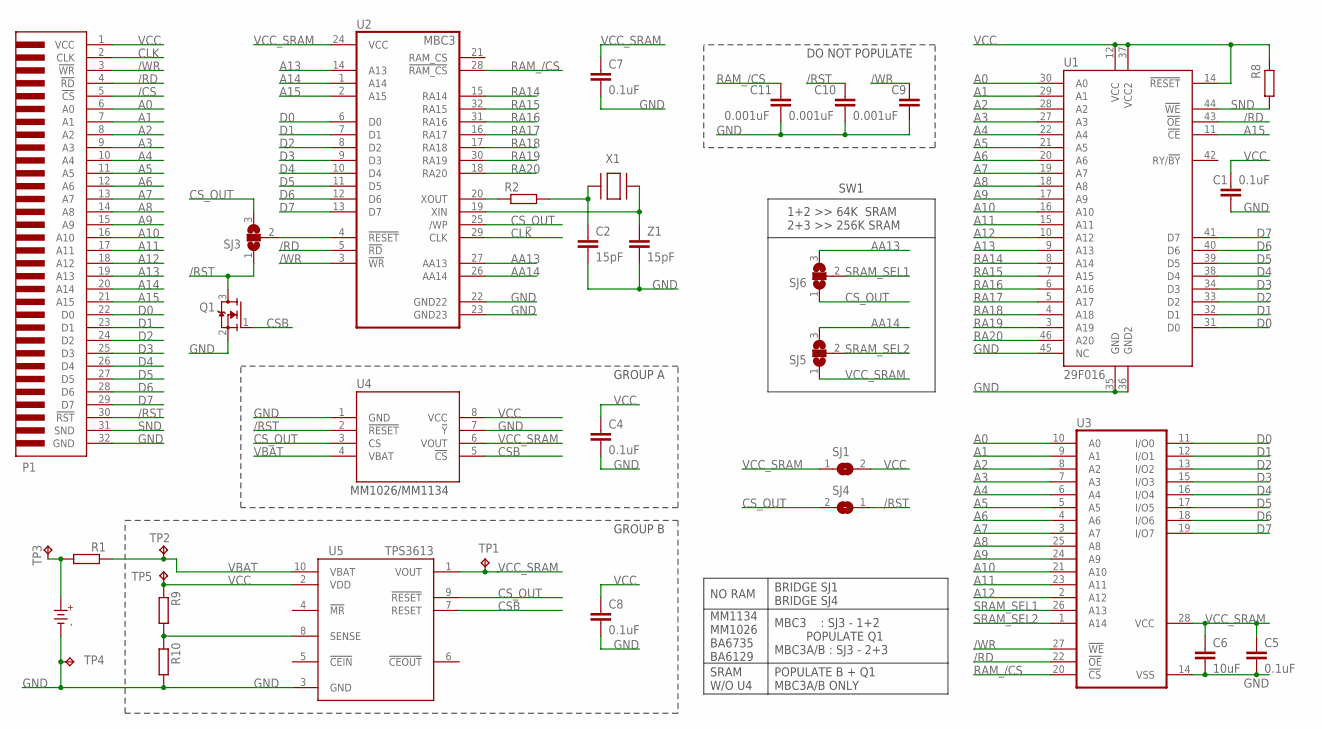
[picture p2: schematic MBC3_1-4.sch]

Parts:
B1: CR2025
C1, C4, C5, C7, C8: 0.1uF; C0603
C2: 15pF; C0603
C6: 10uF; C0603
C9, C10, C11: 0.001uF; C0603
P1: GBC_CARTTAB; GBC_CART_TABBED
Q1: 2N7002; SOT23
R1, R2, R8, R9, R10: RR0603; R0603
SJ1, SJ4: SJ
SJ3, SJ5, SJ6: SJ2W; SJ_2
TP1, TP2, TP3, TP4, TP5: TPB1,27; B1,27
U1: 29F016; TSOP-48
U2: MBC3; QFP-32
U3: 62256_SRAM; SOP-28L
U4: MM1134; SOIC-8
U5: TPS3613; MSOP-10
X1: XTAL-3.2X1.5; XTAL3215
Z1: 15pF; C0603

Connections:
/CS: P1.5 (!CS)
/RD: P1.4 (!RD), U1.43 (!OE), U2.5 (!RD), U3.22 (!OE)
/RST: C10.1, P1.30 (!RST), Q1.3 (D), SJ3.1, SJ4.1, U4.2 (!RESET)
/WR: C9.1, P1.3 (!WR), U2.3 (!WR), U3.27 (!WE)
A0: P1.6 (A0), U1.30 (A0), U3.10 (A0)
A1: P1.7 (A1), U1.29 (A1), U3.9 (A1)
A2: P1.8 (A2), U1.28 (A2), U3.8 (A2)
A3: P1.9 (A3), U1.27 (A3), U3.7 (A3)
A4: P1.10 (A4), U1.22 (A4), U3.6 (A4)
A5: P1.11 (A5), U1.21 (A5), U3.5 (A5)
A6: P1.12 (A6), U1.20 (A6), U3.4 (A6)
A7: P1.13 (A7), U1.19 (A7), U3.3 (A7)
A8: P1.14 (A8), U1.18 (A8), U3.25 (A8)
A9: P1.15 (A9), U1.17 (A9), U3.24 (A9)
A10: P1.16 (A10), U1.16 (A10), U3.21 (A10)
A11: P1.17 (A11), U1.15 (A11), U3.23 (A11)
A12: P1.18 (A12), U1.10 (A12), U3.2 (A12)
A13: P1.19 (A13), U1.9 (A13), U2.14 (A13)
A14: P1.20 (A14), U2.1 (A14)
A15: P1.21 (A15), U1.11 (!CE), U2.2 (A15)
AA13: SJ6.3, U2.27 (AA13)
AA14: SJ5.3, U2.26 (AA14)
CLK: P1.2 (CLK), U2.29 (CLK)
CSB: Q1.1 (G), U4.5 (!CS), U5.7 (RESET)
CS_OUT: SJ3.3, SJ4.2, SJ6.1, U2.25 (/WP), U4.3 (CS), U5.9 (!RESET)
D0: P1.22 (D0), U1.31 (D0), U2.6 (D0), U3.11 (I/O0)
D1: P1.23 (D1), U1.32 (D1), U2.7 (D1), U3.12 (I/O1)
D2: P1.24 (D2), U1.33 (D2), U2.8 (D2), U3.13 (I/O2)
D3: P1.25 (D3), U1.34 (D3), U2.9 (D3), U3.15 (I/O3)
D4: P1.26 (D4), U1.38 (D4), U2.10 (D4), U3.16 (I/O4)
D5: P1.27 (D5), U1.39 (D5), U2.11 (D5), U3.17 (I/O5)
D6: P1.28 (D6), U1.40 (D6), U2.12 (D6), U3.18 (I/O6)
D7: P1.29 (D7), U1.41 (D7), U2.13 (D7), U3.19 (I/O7)
GND: B1.-, C1.2, C2.2, C4.2, C5.2, C6.2, C7.2, C8.2, C9.2, C10.2, C11.2, P1.32 (GND), Q1.2 (S), R10.2, TP4.TP, U1.35 (GND), U1.36 (GND2), U1.45 (NC), U2.22 (GND22), U2.23 (GND23), U3.14 (VSS), U4.1 (GND), U4.7 (!Y), U5.3 (GND), Z1.2
unnamed: SJ3.2, U2.4 (!RESET)
unnamed: B1.+, R1.2, TP3.TP
unnamed: R2.1, U2.20 (XOUT)
unnamed: C2.1, R2.2, X1.P$2
unnamed: U2.19 (XIN), X1.P$1, Z1.1
unnamed: R9.2, R10.1, U5.8 (SENSE)
RA14: U1.8 (A14), U2.15 (RA14)
RA15: U1.7 (A15), U2.32 (RA15)
RA16: U1.6 (A16), U2.31 (RA16)
RA17: U1.5 (A17), U2.16 (RA17)
RA18: U1.4 (A18), U2.17 (RA18)
RA19: U1.3 (A19), U2.30 (RA19)
RA20: U1.46 (A20), U2.18 (RA20)
RAM_/CS: C11.1, U2.28 (!RAM_CS), U3.20 (!CS)
SND: P1.31 (SND), R8.2, U1.44 (!WE)
SRAM_SEL1: SJ6.2, U3.26 (A13)
SRAM_SEL2: SJ5.2, U3.1 (A14)
VBAT: R1.1, TP2.TP, U4.4 (VBAT), U5.10 (VBAT)
VCC: C1.1, C4.1, C8.1, P1.1 (VCC), R8.1, R9.1, SJ1.2, TP5.TP, U1.12 (VCC), U1.14 (!RESET), U1.37 (VCC2), U4.8 (VCC), U5.2 (VDD)
VCC_SRAM: C5.1, C6.1, C7.1, SJ1.1, SJ5.1, TP1.TP, U2.24 (VCC), U3.28 (VCC), U4.6 (VOUT), U5.1 (VOUT)

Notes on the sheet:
GROUP B
NO RAM
BRIDGE SJ1 BRIDGE SJ4
MM1134 MM1026 BA6735 BA6129
MBC3 : SJ3 - 1+2 POPULATE Q1 MBC3A/B : SJ3 - 2+3
SRAM W/O U4
POPULATE B + Q1 MBC3A/B ONLY
1+2 >> 64K SRAM 2+3 >> 256K SRAM
MM1026/MM1134
GROUP A
DO NOT POPULATE
SW1

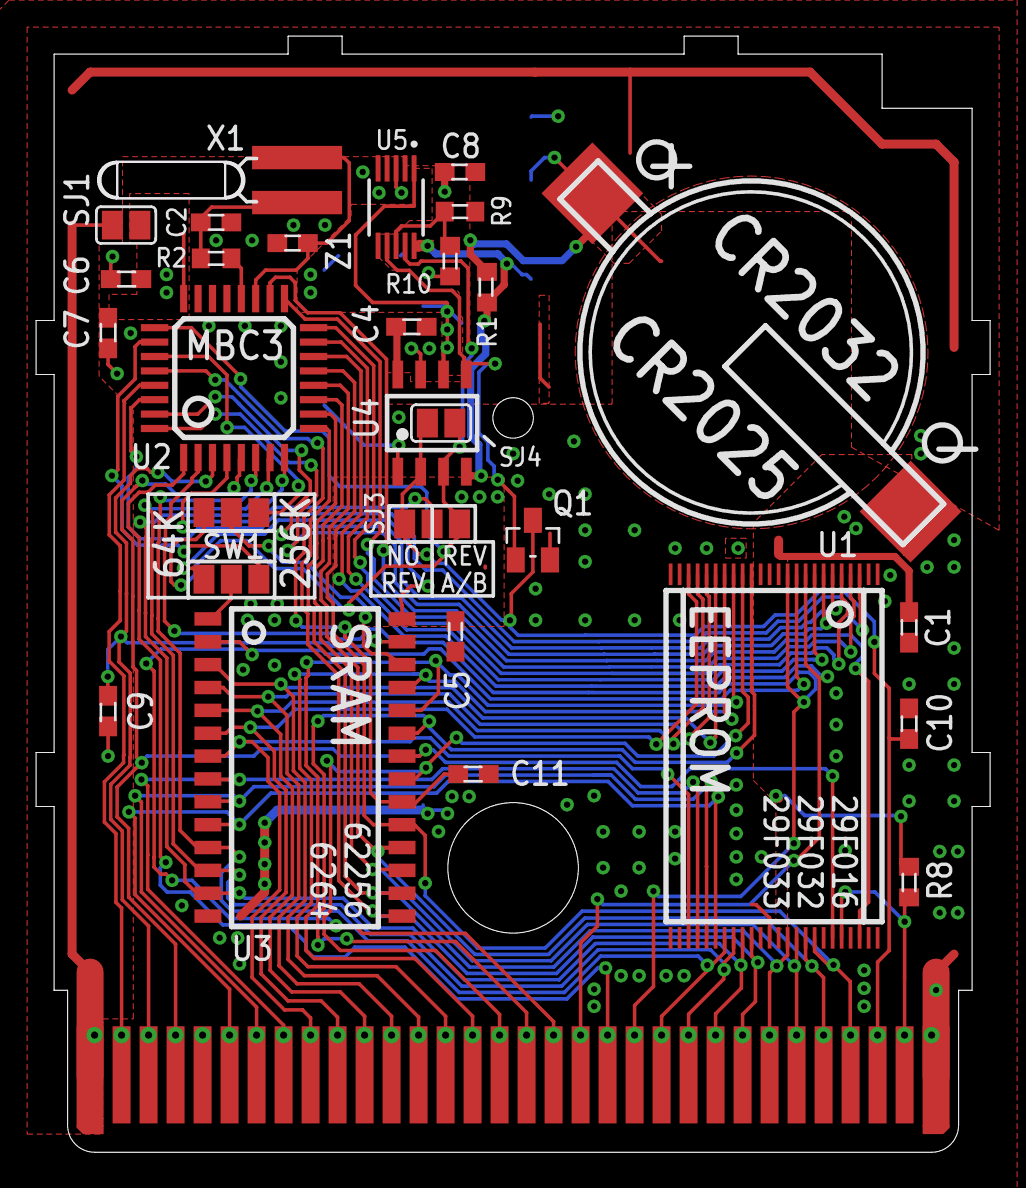
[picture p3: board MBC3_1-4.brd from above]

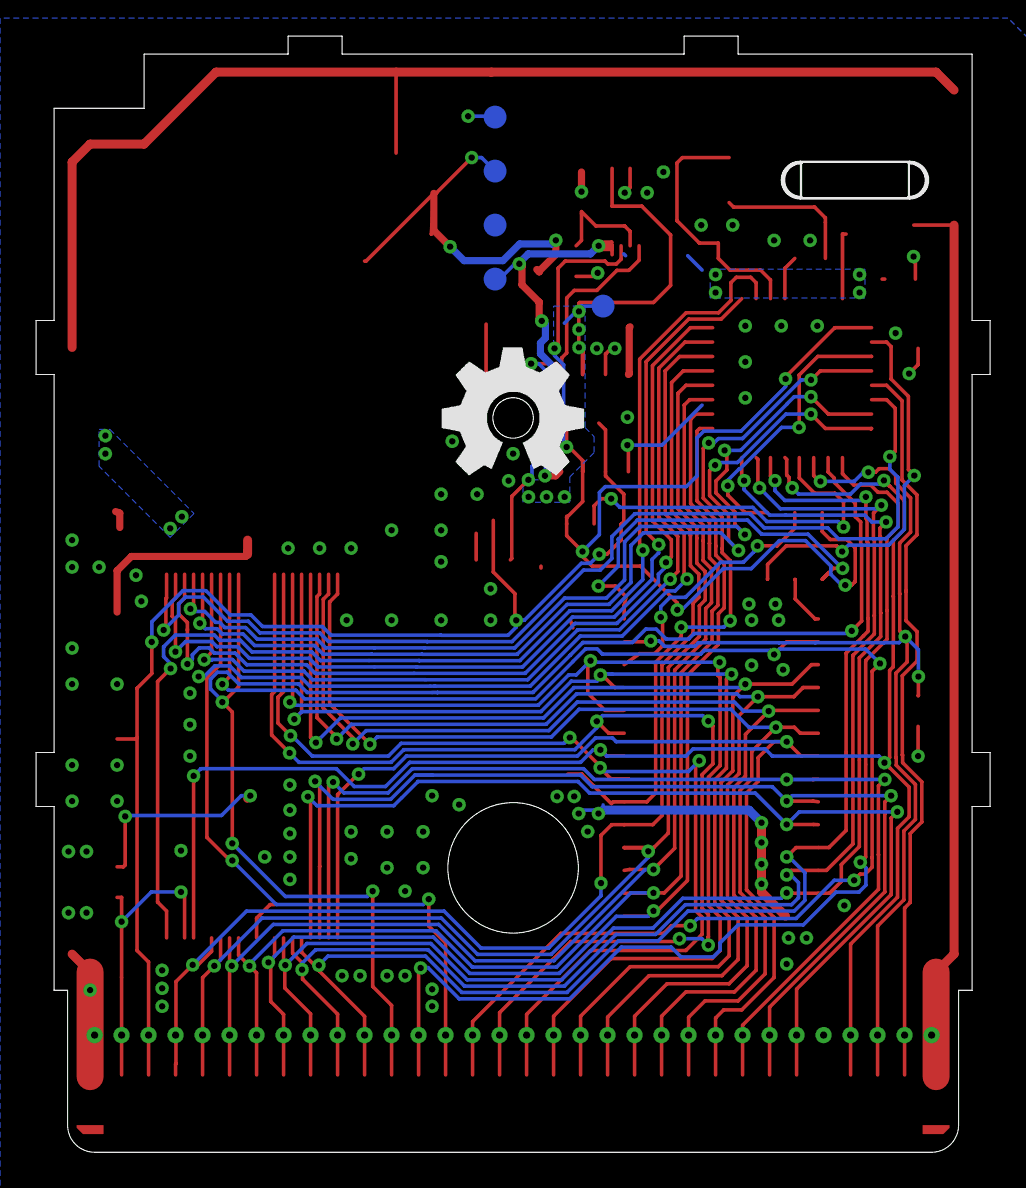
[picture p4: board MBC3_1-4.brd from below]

Board: 2 copper layers, 53.0 x 62.0 mm, 35 parts (5 on the bottom side), 53 nets.
